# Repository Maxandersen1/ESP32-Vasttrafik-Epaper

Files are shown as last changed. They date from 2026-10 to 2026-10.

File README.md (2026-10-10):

# ESP32 Västtrafik and Weather E-Paper Departure Board

An ultra-low-power departure monitor for Swedish public transit (Västtrafik) and local weather forecasts (Open-Meteo), displayed on a Waveshare 4.2-inch black-and-white E-Paper screen and powered by an ESP32-C3 Supermini.

Designed to fit inside a picture frame with a 3D-printed enclosure, running for weeks on rechargeable lithium batteries.

CAD files designed to fit "Fotoram Berlin" 9 x 12 cm available in Clas Ohlson in store or online at:  [Clas](https://www.clasohlson.com/se/p/34-4187-11)

---

## Photos

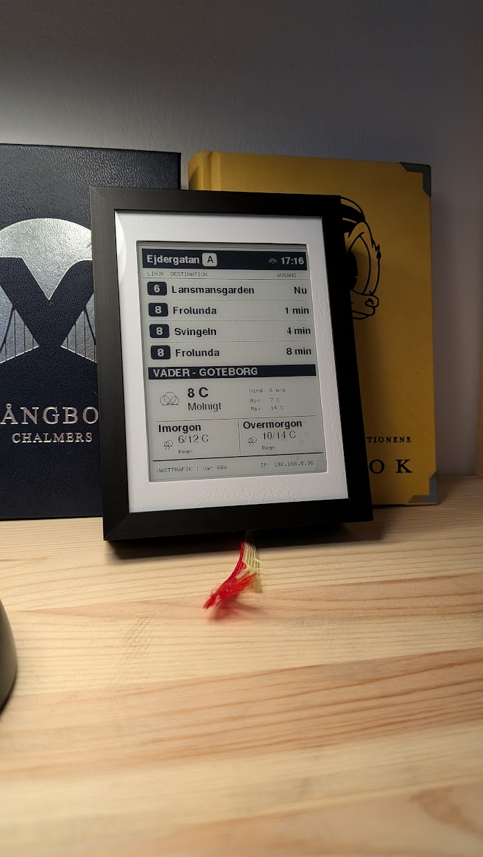
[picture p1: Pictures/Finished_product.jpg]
Departure Board

*Live display showing upcoming departures, current weather, and multi-day forecast.*

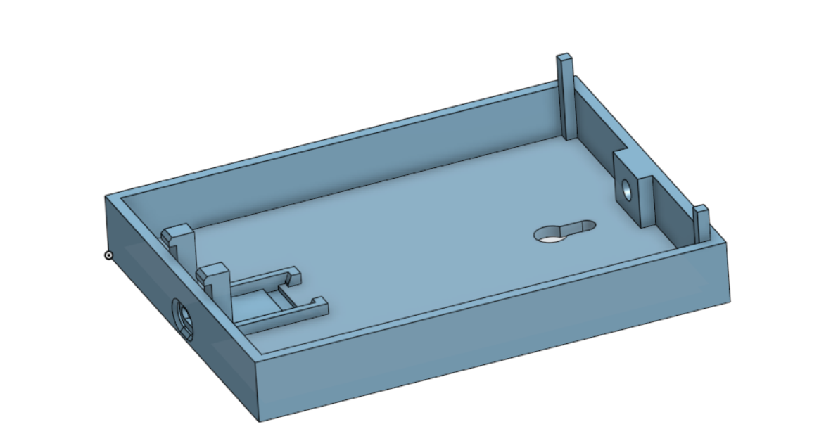
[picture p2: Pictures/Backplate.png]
Enclosure Back

*Custom 3D-printed slim mounting frame and electronics bay.*

---

## Features

- Real-Time Departures: Connects to Västtrafik API v4 to fetch live tram and bus departures, line designations, destinations, and remaining minutes.
- Weather Forecast: Integrated Open-Meteo API displaying current temperature, weather icons, wind speeds, and next two days forecast.
- Power Management:
  - Timer Deep Sleep: The ESP32 enters deep sleep between updates, drawing only around 30 to 50 uA during standby.
  - Fast WiFi Reconnection: Caches WiFi channel and router BSSID in RTC memory to reconnect in under 0.8 seconds.
  - Night Rest Mode: Automatically activates between 00:30 and 06:00. Displays a dedicated night screen showing tomorrow's forecast and remains in deep sleep until morning.
- Clean Portrait Typography: 300x400 layout optimized for high contrast, Swedish ASCII sanitization, and clean line badges.
- Boot Safeguard: Includes a 3-second initialization delay on cold boot to ensure reliable USB flashing without sleep interruptions.

---

## Hardware Requirements

- Microcontroller: ESP32-C3 Supermini (or standard ESP32 / ESP32-S3)
- Display: Waveshare 4.2-inch E-Paper Module (Black/White, SSD1683 / GDEY042T81, 400x300 pixels)
- Power: 3.7V LiPo pouch cell or 18650 Li-ion battery with a TP4056 USB-C charging board
- Frame / Enclosure: Picture frame with 3D-printed mounting brackets

In order to achieve the low power draw the led's from the ESP32 and TP4056 were removed 
---

## Wiring and Pinout

| Waveshare 4.2" E-Paper | ESP32-C3 Supermini Pin | Description |
| :--- | :--- | :--- |
| VCC | 3V3 | 3.3V Power |
| GND | GND | Ground |
| CLK / SCK | GPIO 4 | SPI Clock |
| DIN / MOSI | GPIO 6 | SPI MOSI (Data) |
| CS | GPIO 7 | Chip Select |
| DC | GPIO 5 | Data / Command |
| RST | GPIO 3 | Hardware Reset |
| BUSY | GPIO 1 | Busy Status Signal |

# Schematic 
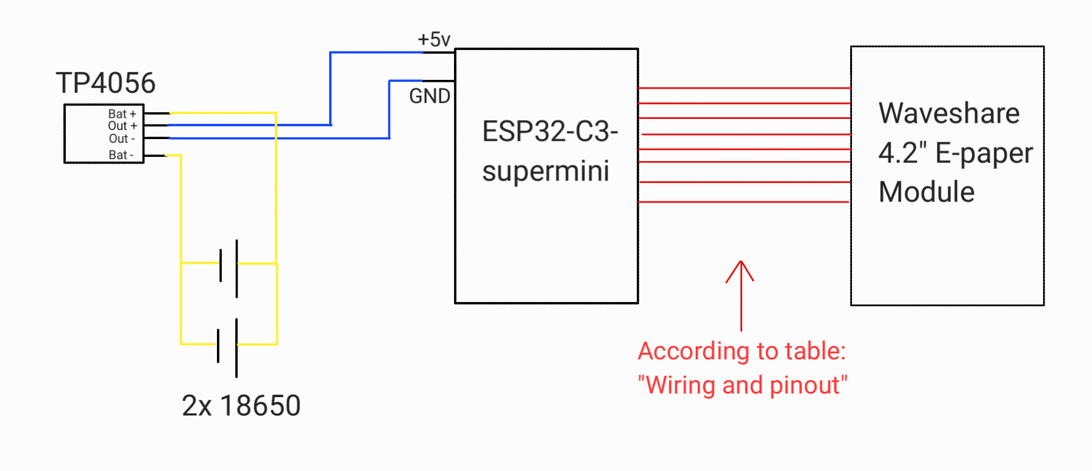
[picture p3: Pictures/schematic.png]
Schematic


---

## 3D CAD Files

CAD models for the custom frame and component brackets are provided in the `cad/` directory:
- STEP (`.step` / `.stp`): Recommended for parametric CAD tools (Fusion 360, SolidWorks, FreeCAD).
---

## Software Dependencies

Install the following libraries using the Arduino Library Manager:

1. GxEPD2 (by Jean-Marc Zingg)
2. Adafruit GFX Library
3. ArduinoJson (version 6 or 7)

Board definition in Arduino IDE:
- ESP32 by Espressif Systems (Select `ESP32C3 Dev Module`)

---

## Setup and Configuration

1. Clone or download this repository.
2. Open `config.h` and update the placeholders:

```cpp
// WiFi Configuration
#define WIFI_SSID           "YOUR_WIFI_SSID"
#define WIFI_PASSWORD       "YOUR_WIFI_PASSWORD"

// Västtrafik OAuth2 API Credentials
#define CLIENT_ID           "YOUR_CLIENT_ID"
#define CLIENT_SECRET       "YOUR_CLIENT_SECRET"

// Stop Location and Platform
#define STOP_GID            "9021014002150000"  // Stop area GID
#define STOP_NAME           "Ejdergatan"        // Header display name
#define TARGET_PLATFORM     'A'                 // Platform filter ('A', 'B', etc.)

// Weather Coordinates
#define LATITUDE            "57.72"             // Local latitude
#define LONGITUDE           "12.01"             // Local longitude
---

## 📄 Licens

Detta projekt är öppen källkod under [MIT-licensen](LICENSE). Använd och modifiera fritt!

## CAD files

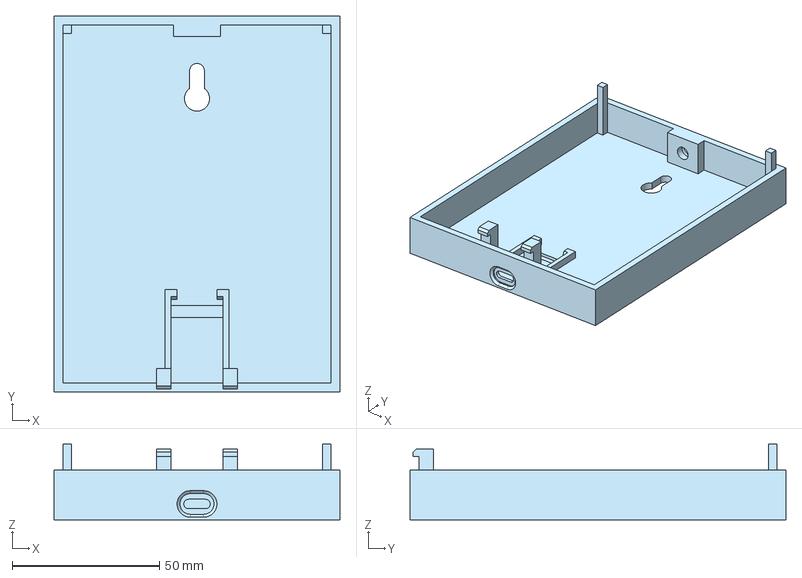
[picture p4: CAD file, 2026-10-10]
Cad/backplate.step
97.0 x 127.5 x 25.7 mm

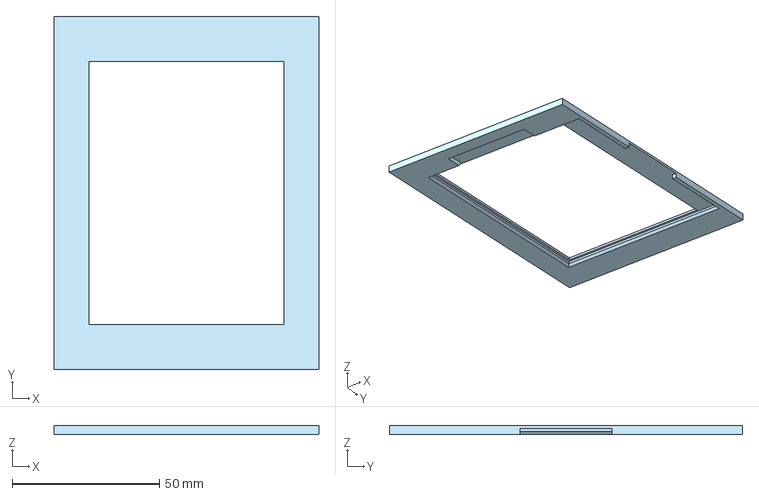
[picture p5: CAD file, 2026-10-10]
Cad/Front_Cover.step
90.0 x 120.0 x 2.90 mm

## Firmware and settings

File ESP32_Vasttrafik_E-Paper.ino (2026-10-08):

/*
 *  Västtrafik + Väder E-Paper Departure Monitor
 *  -------------------------------------------------------------
 *  En strömsnål avgångstavla för Västtrafik & väderprognos (Open-Meteo)
 *  byggd för ESP32-C3 Supermini och Waveshare 4.2" E-Paper display.
 *
 *  Funktioner:
 *  - E-Ink skärm i portrait-läge (300 x 400 px)
 *  - Snabb WiFi-anslutning med kanal- och BSSID-caching i RTC-minnet (<0.8s)
 *  - Timer Deep Sleep mellan uppdateringar dagtid (sparar >95% batteri)
 *  - Nattvila (00:30 - 06:00) med dedikerad nattvilaskärm & morgonens väderprognos
 *  - 3 sekunders programmeringsbuffert vid kallstart för enkel USB-flashing
 *
 *  Skapad av: Max & Antigravity (Google DeepMind)
 *  Licens: MIT
 */

#include <Arduino.h>
#include <WiFi.h>
#include <SPI.h>
#include <esp_sleep.h>

#include "config.h"
#include "display_ui.h"
#include "vasttrafik_api.h"
#include "weather_service.h"

// Objekt för Västtrafik & Väder
VasttrafikService vasttrafik;
WeatherService    weather;

DepartureItem departures[MAX_DEPARTURES];
size_t        departureCount = 0;

uint32_t lastRefreshMillis = 0;

// Variabler bevarade i ESP32 RTC-minnet under Deep Sleep
RTC_DATA_ATTR uint32_t rtcBootCount = 0;
RTC_DATA_ATTR bool     rtcNightScreenDrawn = false;
RTC_DATA_ATTR uint8_t  rtcWifiChannel = 0;
RTC_DATA_ATTR uint8_t  rtcWifiBSSID[6] = {0};
RTC_DATA_ATTR bool     rtcWifiValid = false;

// =============================================================================
//  NÄTVERKSANSLUTNING MELLAN DEEP SLEEP (SNABB RECONNECT)
// =============================================================================
bool connectWiFi() {
  if (WiFi.status() == WL_CONNECTED) return true;

  WiFi.mode(WIFI_STA);

  // Snabbanslutning med cachad kanal & BSSID sparar 2-3 sekunders söktid
  if (rtcWifiValid && rtcWifiChannel > 0) {
    WiFi.begin(WIFI_SSID, WIFI_PASSWORD, rtcWifiChannel, rtcWifiBSSID, true);
  } else {
    WiFi.begin(WIFI_SSID, WIFI_PASSWORD);
  }

  Serial.printf("[WiFi] Ansluter till '%s'...", WIFI_SSID);

  uint32_t start = millis();
  while (WiFi.status() != WL_CONNECTED && millis() - start < WIFI_TIMEOUT_MS) {
    delay(100);
    Serial.print(".");
  }
  Serial.println();

  if (WiFi.status() == WL_CONNECTED) {
    rtcWifiChannel = WiFi.channel();
    memcpy(rtcWifiBSSID, WiFi.BSSID(), 6);
    rtcWifiValid = true;

    Serial.printf("[WiFi] OK! IP: %s (Kanal %d, RSSI %d dBm)\n",
                  WiFi.localIP().toString().c_str(),
                  rtcWifiChannel,
                  WiFi.RSSI());
    return true;
  }

  Serial.println("[WiFi] Misslyckades att ansluta.");
  return false;
}

// =============================================================================
//  NATTVILA LOGIK (00:30 - 06:00)
// =============================================================================
bool checkIsNightTime() {
  struct tm now;
  if (!getLocalTime(&now, 50)) return false;

  int cur   = now.tm_hour * 60 + now.tm_min;
  int start = NIGHT_START_HOUR * 60 + NIGHT_START_MIN;
  int end   = NIGHT_END_HOUR * 60 + NIGHT_END_MIN;

  if (start < end) {
    return (cur >= start && cur < end);
  } else {
    return (cur >= start || cur < end);
  }
}

uint32_t getSecondsUntilNightEnd() {
  struct tm now;
  if (!getLocalTime(&now, 50)) return 60;

  int currentSecOfDay = now.tm_hour * 3600 + now.tm_min * 60 + now.tm_sec;
  int targetSecOfDay  = NIGHT_END_HOUR * 3600 + NIGHT_END_MIN * 60;

  if (targetSecOfDay > currentSecOfDay) {
    return (targetSecOfDay - currentSecOfDay);
  } else {
    return ((24 * 3600 - currentSecOfDay) + targetSecOfDay);
  }
}

// Uppdatera väder och avgångar samt rita om skärmen
void updateAndRender() {
  weather.update();

  if (vasttrafik.getDepartures(departures, MAX_DEPARTURES, departureCount)) {
    String currentTime = vasttrafik.getCurrentTimeString();
    renderDepartureAndWeatherBoard(departures, departureCount, weather.getData(), currentTime, true);
  } else {
    Serial.println("[Main] Kunde inte hämta avgångar.");
    renderErrorScreen("API-fel", "Kunde inte hamta avgangar fran Vasttrafik");
  }
}

// =============================================================================
//  SETUP & LOOP
// =============================================================================
void setup() {
  Serial.begin(115200);
  rtcBootCount++;

  Serial.println("\n==========================================");
  Serial.printf("  Västtrafik + Väder E-Paper Monitor (Boot #%u)\n", rtcBootCount);
  Serial.println("==========================================");

  // Vid kallstart (första gången den kopplas in via USB eller batteri):
  // 3 sekunders paus så att USB och Serial hinner ansluta för ny programmering
  if (rtcBootCount == 1) {
    Serial.println("[System] Första uppstart. Pausar 3s för USB-programmering...");
    delay(3000);
  }

  // Initiera SPI-buss för ESP32-C3 Supermini
  SPI.begin(EPD_SCK, -1, EPD_MOSI, EPD_CS);

  // Initiera Waveshare 4.2" E-Paper display
  display.init(115200, true, 2, false);

  if (rtcBootCount == 1 && !rtcNightScreenDrawn) {
    renderConnectingScreen(WIFI_SSID);
  }

  // Anslut till nätverket
  if (!connectWiFi()) {
    renderErrorScreen("WiFi-anslutning misslyckades", "Kontrollera SSID och losenord i config.h");
    if (ENABLE_DEEP_SLEEP) {
      Serial.println("[Main] Somnar 60s innan nytt försök...");
      esp_sleep_enable_timer_wakeup(60ULL * 1000000ULL);
      esp_deep_sleep_start();
    }
    while (true) {
      delay(5000);
      if (connectWiFi()) break;
    }
  }

  // Initiera tidssynkronisering (NTP)
  vasttrafik.initTimeSync();
  delay(500);

  // Uppdatera väder
  weather.update(true);

  // =========================================================================
  // KONTROLL FÖR NATTVILA (KL 00:30 - 06:00)
  // =========================================================================
  if (ENABLE_NIGHT_SLEEP && checkIsNightTime()) {
    char wakeBuf[10];
    snprintf(wakeBuf, sizeof(wakeBuf), "%02d:%02d", NIGHT_END_HOUR, NIGHT_END_MIN);
    String wakeUpStr = String(wakeBuf);
    String currentTime = vasttrafik.getCurrentTimeString();

    if (!rtcNightScreenDrawn) {
      Serial.printf("[Nattvila] Nattvila aktiv! Ritar nattvilaskärm till kl %s...\n", wakeUpStr.c_str());
      renderNightScreen(weather.getData(), currentTime, wakeUpStr);
      rtcNightScreenDrawn = true;
    } else {
      Serial.println("[Nattvila] Nattvilaskärm redan ritad.");
    }

    uint32_t sleepSeconds = getSecondsUntilNightEnd();
    Serial.printf("[Nattvila] Sover i Deep Sleep i %u sekunder (ca %.1f timmar) till kl %s...\n",
                  sleepSeconds, sleepSeconds / 3600.0f, wakeUpStr.c_str());

    WiFi.disconnect(true);
    WiFi.mode(WIFI_OFF);

    if (ENABLE_DEEP_SLEEP) {
      esp_sleep_enable_timer_wakeup((uint64_t)sleepSeconds * 1000000ULL);
      esp_deep_sleep_start();
    } else {
      delay(sleepSeconds * 1000UL);
    }
    return;
  }

  // Dagtid: Nollställ flaggan för nattvilaskärmen
  rtcNightScreenDrawn = false;

  // Gör uppdatering av avgångar och väder
  updateAndRender();

  // =========================================================================
  // DAGTID TIMER DEEP SLEEP (SPARAR >95% BATTERI)
  // =========================================================================
  if (ENABLE_DEEP_SLEEP) {
    Serial.printf("[Power] Allt klart! Stänger av WiFi och sover i Deep Sleep i %d sekunder...\n", REFRESH_INTERVAL_S);
    WiFi.disconnect(true);
    WiFi.mode(WIFI_OFF);

    esp_sleep_enable_timer_wakeup((uint64_t)REFRESH_INTERVAL_S * 1000000ULL);
    esp_deep_sleep_start();
  }

  lastRefreshMillis = millis();
}

void loop() {
  // Körs enbart om ENABLE_DEEP_SLEEP = false
  uint32_t now = millis();

  if (now - lastRefreshMillis >= (REFRESH_INTERVAL_S * 1000UL)) {
    lastRefreshMillis = now;
    Serial.printf("\n[Main] Schemalagd uppdatering (var %d:e sekund)...\n", REFRESH_INTERVAL_S);
    if (WiFi.status() != WL_CONNECTED) {
      connectWiFi();
    }
    updateAndRender();
  }
  delay(100);
}

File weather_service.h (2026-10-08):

#pragma once

#include <Arduino.h>
#include <WiFi.h>
#include <HTTPClient.h>
#include <ArduinoJson.h>
#include "config.h"

// Struktur för väderdata (Open-Meteo API)
struct WeatherInfo {
  bool   valid = false;
  float  currentTemp = 0.0;
  int    currentCode = 0;
  float  currentWind = 0.0; // m/s
  String currentDesc = "Klart";

  // Idag
  float  todayMax = 0.0;
  float  todayMin = 0.0;

  // Imorgon
  float  tomorrowMax = 0.0;
  float  tomorrowMin = 0.0;
  int    tomorrowCode = 0;
  String tomorrowDesc = "";

  // I övermorgon
  float  dayAfterMax = 0.0;
  float  dayAfterMin = 0.0;
  int    dayAfterCode = 0;
  String dayAfterDesc = "";
};

class WeatherService {
private:
  WeatherInfo _data;
  uint32_t    _lastFetchMs = 0;
  const uint32_t UPDATE_INTERVAL_MS = 15 * 60 * 1000UL; // Uppdatera var 15:e minut

  String decodeWmoCode(int code) {
    switch (code) {
      case 0:  return "Klart";
      case 1:  return "Mestadels klart";
      case 2:  return "Halvklart";
      case 3:  return "Molnigt";
      case 45:
      case 48: return "Dimmigt";
      case 51:
      case 53:
      case 55: return "Duggregn";
      case 61:
      case 63:
      case 65: return "Regn";
      case 66:
      case 67: return "Underkylt regn";
      case 71:
      case 73:
      case 75: return "Snofall";
      case 77: return "Kornsnö";
      case 80:
      case 81:
      case 82: return "Regnskurar";
      case 85:
      case 86: return "Snobyar";
      case 95:
      case 96:
      case 99: return "Aska";
      default: return (code > 60 && code < 70) ? "Regn" : "Molnigt";
    }
  }

public:
  WeatherService() {}

  WeatherInfo getData() {
    return _data;
  }

  bool update(bool force = false) {
    uint32_t now = millis();
    if (!force && _data.valid && (now - _lastFetchMs < UPDATE_INTERVAL_MS)) {
      return true; // Använd cachad data
    }

    if (WiFi.status() != WL_CONNECTED) {
      return false;
    }

    WiFiClient client;
    HTTPClient http;

    // Open-Meteo REST API (Gratis, ingen API-nyckel krävs)
    String url = "http://api.open-meteo.com/v1/forecast?latitude=" LATITUDE "&longitude=" LONGITUDE
                 "&current=temperature_2m,weather_code,wind_speed_10m"
                 "&daily=weather_code,temperature_2m_max,temperature_2m_min"
                 "&forecast_days=3&timezone=auto";

    if (!http.begin(client, url)) {
      Serial.println("[Väder] Kunde inte ansluta till Open-Meteo");
      return false;
    }

    http.setTimeout(8000);
    int httpCode = http.GET();

    if (httpCode != 200) {
      Serial.printf("[Väder] HTTP %d från Open-Meteo\n", httpCode);
      http.end();
      return false;
    }

    String payload = http.getString();
    http.end();

#if ARDUINOJSON_VERSION_MAJOR >= 7
    JsonDocument doc;
#else
    DynamicJsonDocument doc(4096);
#endif
    DeserializationError error = deserializeJson(doc, payload);

    if (error) {
      Serial.printf("[Väder] JSON-parsning misslyckades: %s\n", error.c_str());
      return false;
    }

    _data.currentTemp = doc["current"]["temperature_2m"] | 0.0f;
    _data.currentCode = doc["current"]["weather_code"] | 0;
    float windKmH     = doc["current"]["wind_speed_10m"] | 0.0f;
    _data.currentWind = windKmH / 3.6f;
    _data.currentDesc = decodeWmoCode(_data.currentCode);

    _data.todayMax = doc["daily"]["temperature_2m_max"][0] | _data.currentTemp;
    _data.todayMin = doc["daily"]["temperature_2m_min"][0] | _data.currentTemp;

    _data.tomorrowMax  = doc["daily"]["temperature_2m_max"][1] | 0.0f;
    _data.tomorrowMin  = doc["daily"]["temperature_2m_min"][1] | 0.0f;
    _data.tomorrowCode = doc["daily"]["weather_code"][1] | 0;
    _data.tomorrowDesc = decodeWmoCode(_data.tomorrowCode);

    _data.dayAfterMax  = doc["daily"]["temperature_2m_max"][2] | 0.0f;
    _data.dayAfterMin  = doc["daily"]["temperature_2m_min"][2] | 0.0f;
    _data.dayAfterCode = doc["daily"]["weather_code"][2] | 0;
    _data.dayAfterDesc = decodeWmoCode(_data.dayAfterCode);

    _data.valid = true;
    _lastFetchMs = now;
    Serial.printf("[Väder] OK! Temp: %.1f C, %s (Vind: %.1f m/s)\n",
                  _data.currentTemp, _data.currentDesc.c_str(), _data.currentWind);
    return true;
  }
};

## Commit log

2026-10-10 Fix image path case in README.md
    Corrected the case of the 'Pictures' directory in the image path.
2026-10-10 Add schematic section with image reference
    Added schematic image reference to README.
2026-10-10 Revise battery life and CAD file information in README
    Updated battery life description and added CAD file details.
2026-10-10 Fix image extension and add low power draw note
    Updated image file extension for enclosure back and added note about low power draw modifications.
2026-10-10 Fix formatting of Schematic section in README
